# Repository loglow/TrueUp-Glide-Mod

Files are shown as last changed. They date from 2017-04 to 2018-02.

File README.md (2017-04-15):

# TrueUp-Glide-Mod

This is a modification of the [TrueUp Glide](http://www.openbuilds.com/builds/trueup-glide.3938/) 3D printer design by [Keith Davis](http://www.openbuilds.com/members/keith-davis.246/).

This mod differs from the source build in the following respects:

- Utilizes the [Bondtech BMG Extruder](http://shop.bondtech.se/ec/extruders/bmg-extruder.html) module
- Incorporates a [Raspberry Pi 3 Model B](https://www.raspberrypi.org/products/raspberry-pi-3-model-b/) running [OctoPi](https://octopi.octoprint.org) into the control box
- Includes an optional printed enclosure for the power supply unit
- Consolidates several printed parts and introduces several new ones
- Utilizes heat-set threaded inserts in several instances
- Minor redesign and dimensional cleanup of most printed parts
- Dimensionally accurate and logically organized master SketchUp file

This build is currently a work-in-progress and has not yet been fully tested. The complete BOM will be added in spreadsheet form as soon as possible.

## License

Adapted from [TrueUp Glide](http://www.openbuilds.com/builds/trueup-glide.3938/) and [TrueUp Kit Version](http://www.openbuilds.com/builds/trueup-kit-version.4779/) by [Keith Davis](http://www.openbuilds.com/members/keith-davis.246/) and licensed [Creative Commons BY-NC-SA](https://creativecommons.org/licenses/by-nc-sa/4.0/)

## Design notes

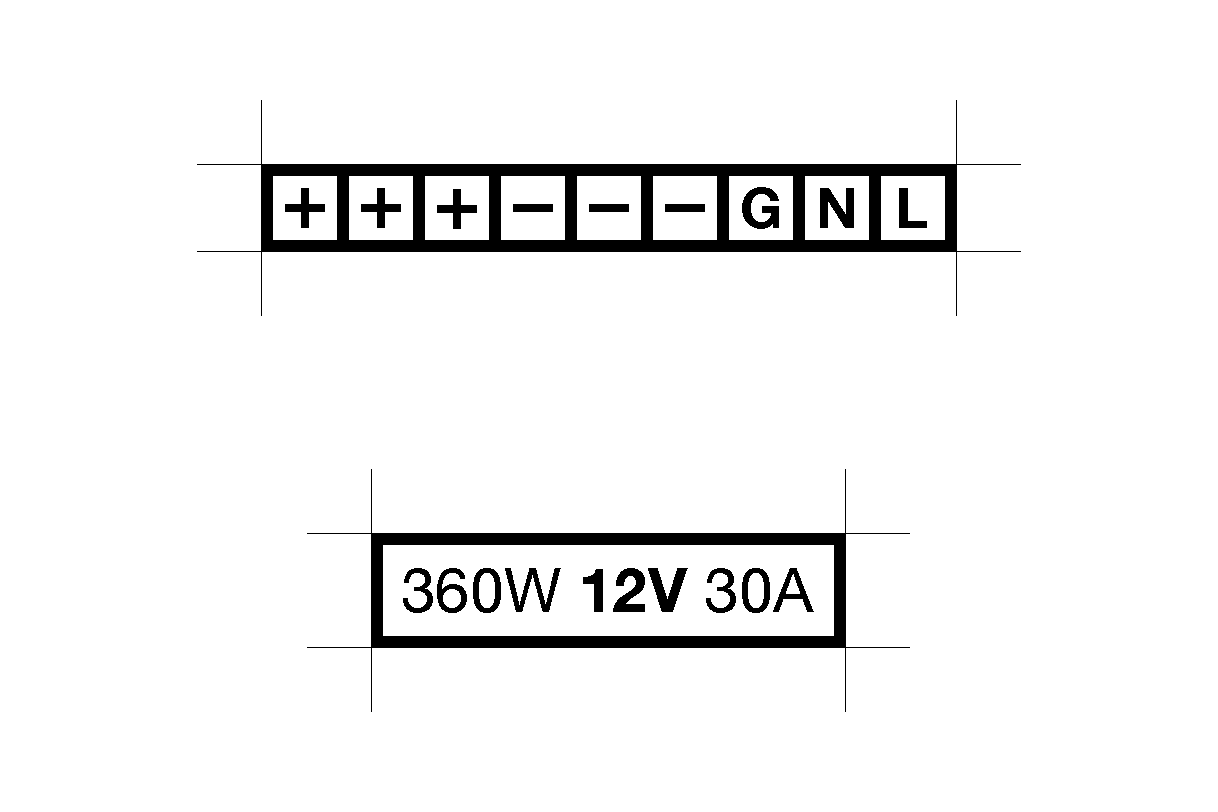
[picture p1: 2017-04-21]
PSU Label.png

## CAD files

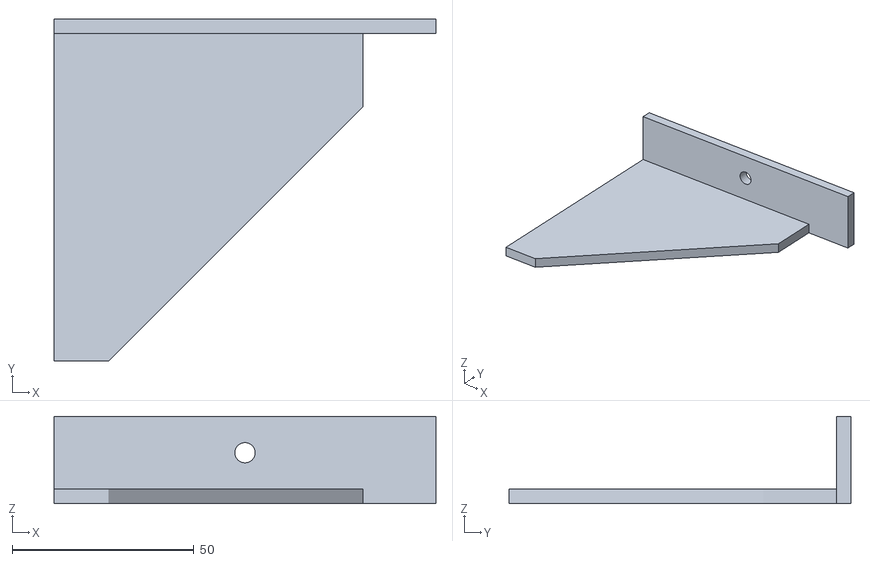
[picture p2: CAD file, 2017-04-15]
STL/Y Assembly Jig.stl
105.0 x 94.0 x 24.0

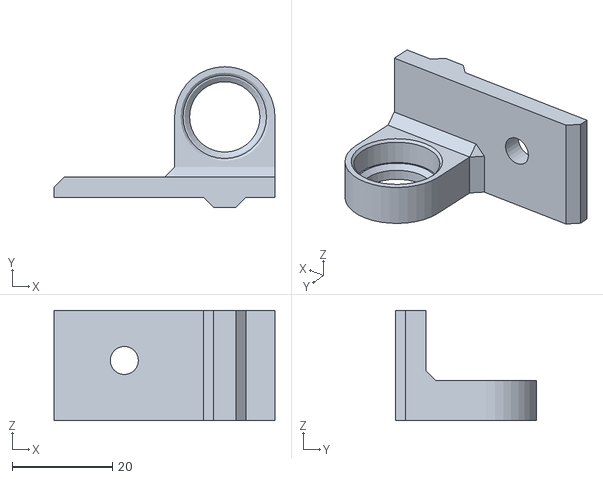
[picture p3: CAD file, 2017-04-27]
STL/Z Protector Bracket, Right.stl
44.0 x 28.0 x 22.0

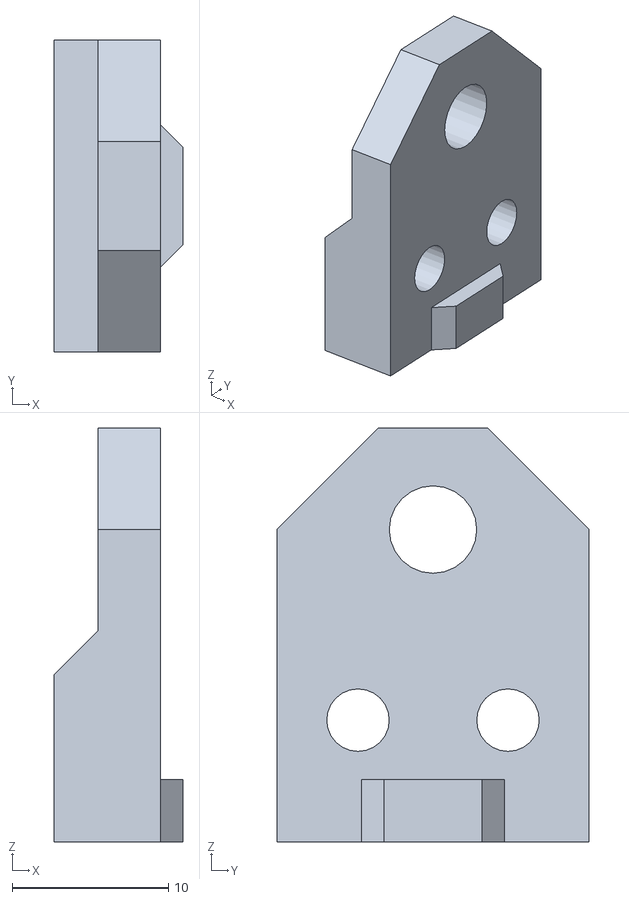
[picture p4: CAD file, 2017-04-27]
STL/Y Endstop Bracket.stl
8.26 x 20.0 x 26.5

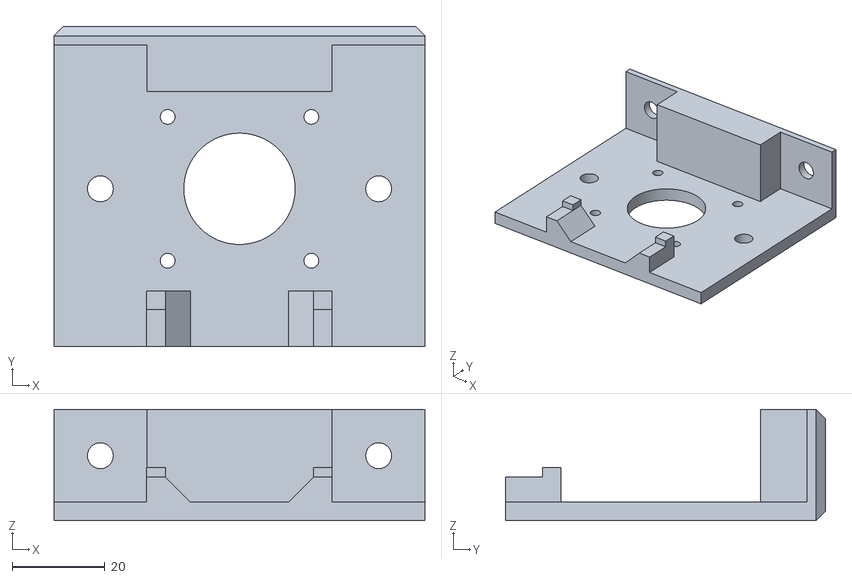
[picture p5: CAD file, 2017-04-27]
STL/Y Motor Mount.stl
80.0 x 69.0 x 24.0

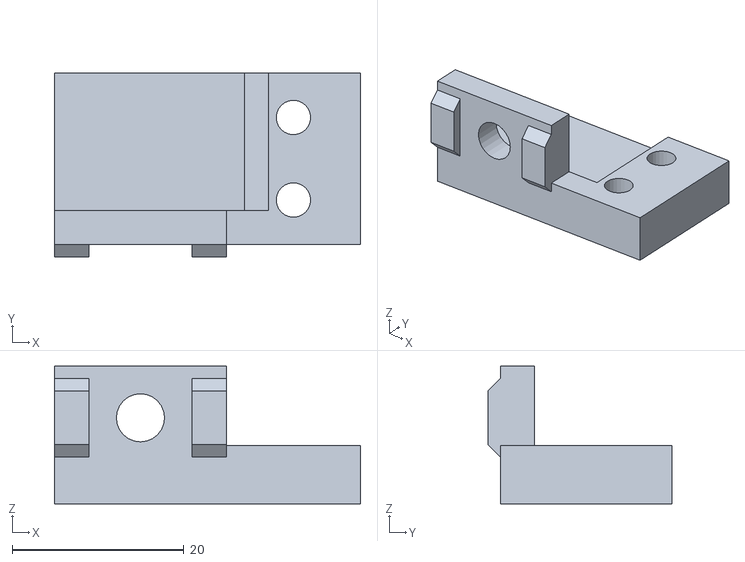
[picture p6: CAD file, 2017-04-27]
STL/X Endstop Bracket.stl
35.6 x 21.5 x 16.0

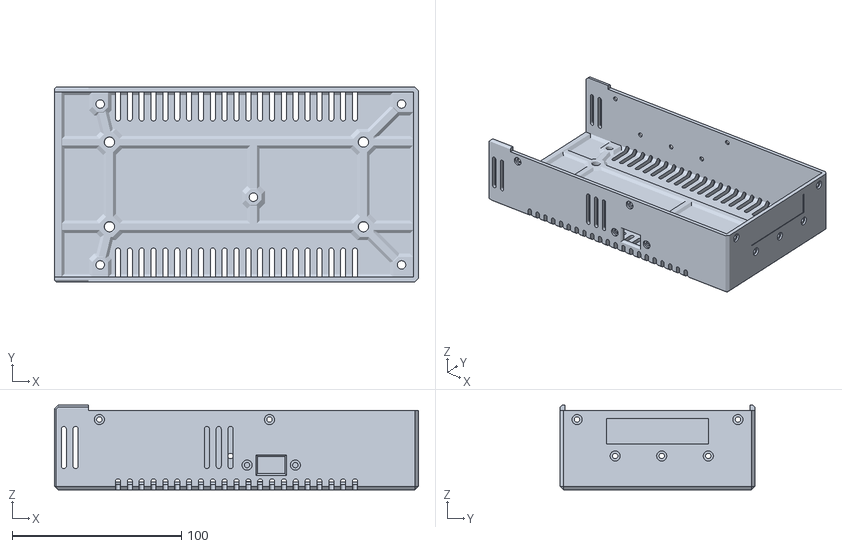
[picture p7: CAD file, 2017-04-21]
STL/PSU Bottom.stl
215.0 x 115.0 x 50.0

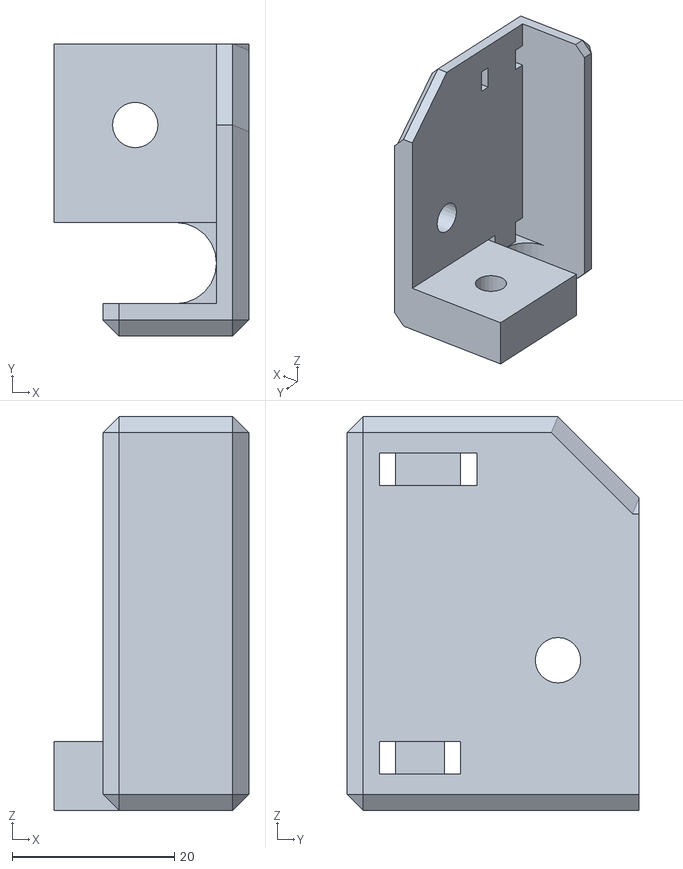
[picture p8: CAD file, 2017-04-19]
STL/X Belt Idler Bracket, Left.stl
24.0 x 36.0 x 48.5

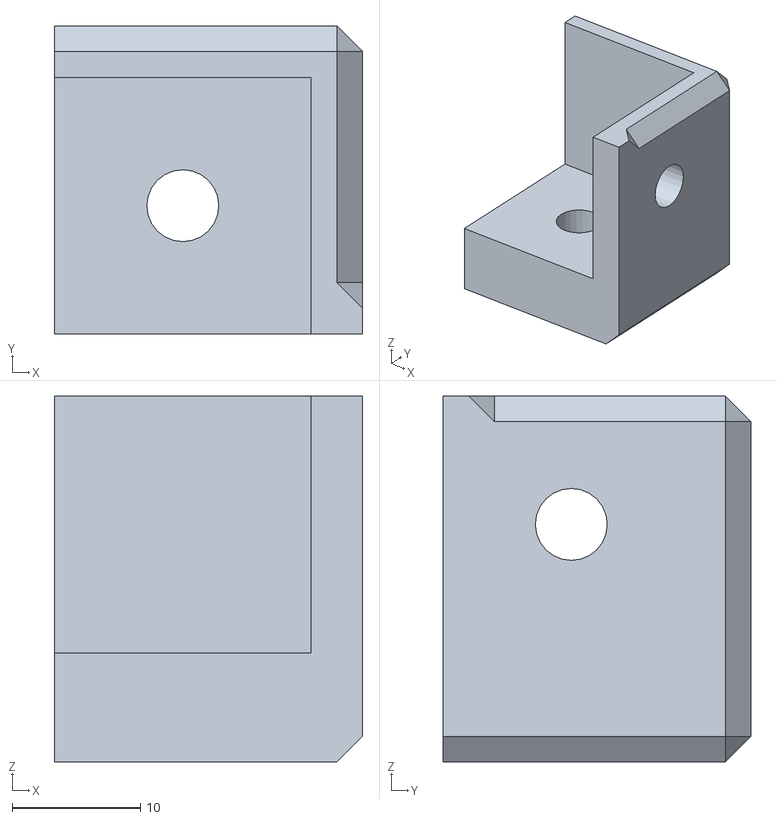
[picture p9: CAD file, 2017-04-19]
STL/X Belt Idler Bracket, Right.stl
24.0 x 24.0 x 28.5

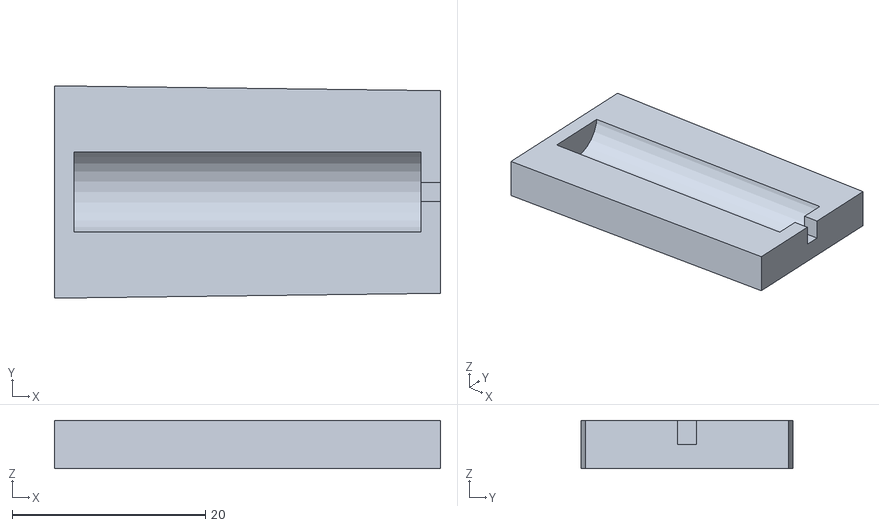
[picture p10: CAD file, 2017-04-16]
STL/Glide Bushing.stl
40.0 x 22.0 x 5.00

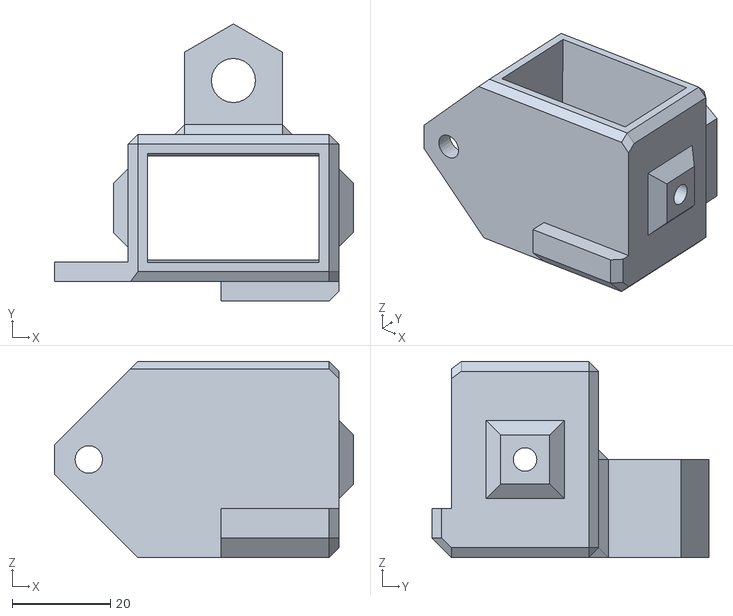
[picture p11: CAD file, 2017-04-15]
STL/Z Glide Body, Right.stl
61.0 x 56.5 x 40.0

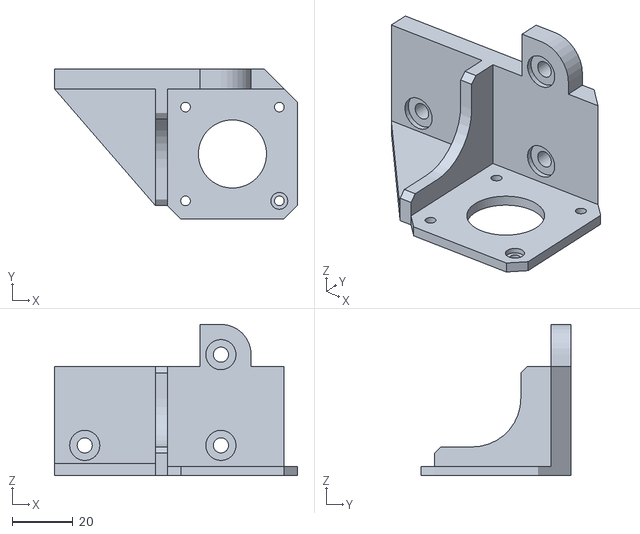
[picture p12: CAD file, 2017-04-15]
STL/Bondtech BMG Extruder Mount.stl
80.3 x 49.6 x 50.0

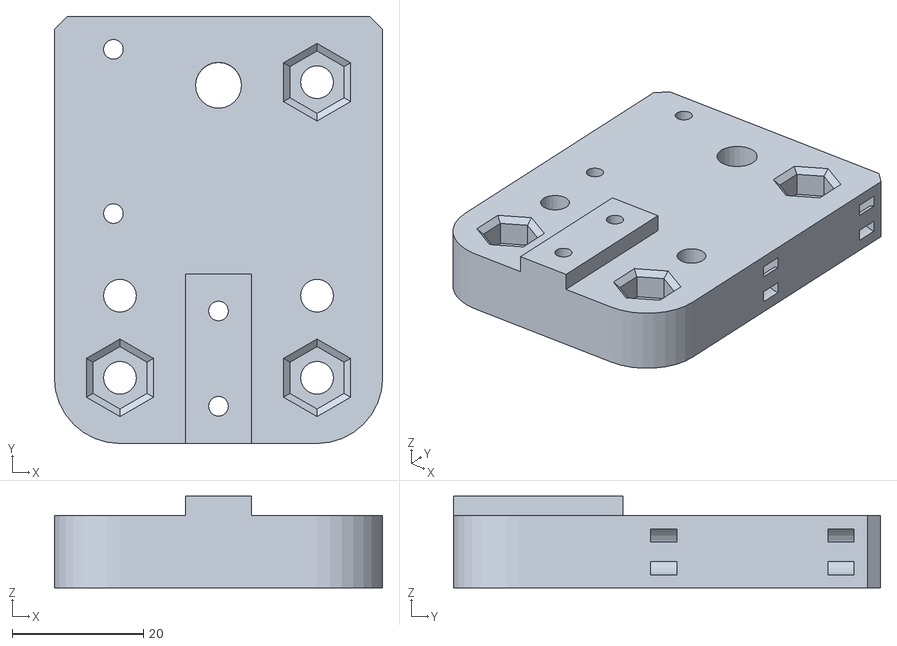
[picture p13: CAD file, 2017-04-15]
STL/X Carriage.stl
50.0 x 65.0 x 14.0

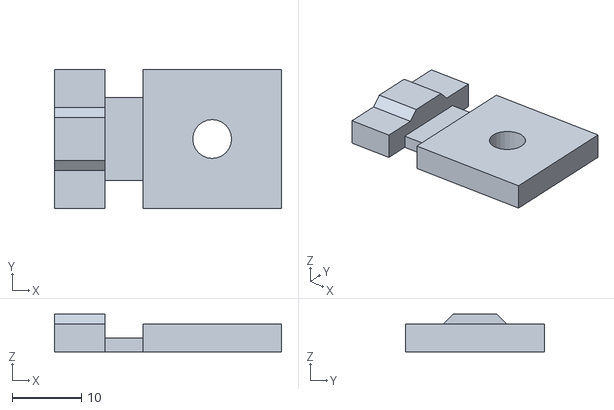
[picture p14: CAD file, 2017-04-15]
STL/Tie Bracket.stl
32.8 x 20.0 x 5.45

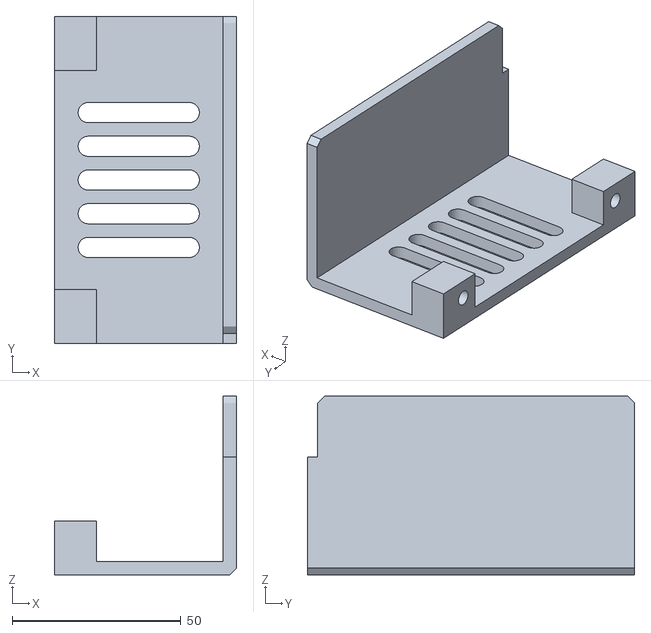
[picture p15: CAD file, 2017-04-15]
STL/PSU Cover.stl
54.0 x 97.0 x 53.0

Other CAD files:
STL/Z Protector Bracket, Left.stl
STL/PSU Mount.stl
STL/Frame Foot.stl
STL/MKS Mount.stl
STL/Control Box Fan Mount.stl
STL/Control Box, Bottom.stl
STL/Control Box, Front.stl
STL/Control Box, Left.stl
STL/Control Box, Right.stl
STL/Control Box, Top.stl
STL/Corner Nut Anchor.stl
STL/Crossover Cover.stl
STL/Front Foot.stl
STL/Handle.stl
STL/Loom Cap.stl
STL/M8 Nut Keeper.stl
STL/PSU Top.stl
STL/Print Fan Nozzle.stl
STL/Print Fan Top.stl
STL/Spool Holder.stl
STL/Spool Mount.stl
STL/Top Corner, Left.stl
STL/Top Corner, Right.stl
STL/X Belt Keeper.stl
STL/X Leveling Jig.stl
STL/X Motor Mount.stl
STL/Y Belt Keeper Flat.stl
STL/Y Belt Keeper Spacer.stl
STL/Y Belt Keeper Teeth.stl
STL/Y Center.stl
STL/Y Idler Bracket.stl
STL/Y Mount Bracket.stl
STL/Z Bearing Mount.stl
STL/Z Endstop Bracket.stl
STL/Z Endstop Screw, Lower.stl
STL/Z Endstop Screw, Upper.stl
STL/Z Glide Body, Left.stl
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

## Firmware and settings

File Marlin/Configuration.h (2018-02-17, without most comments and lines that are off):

#define CONFIGURATION_H
#define CONFIGURATION_H_VERSION 010107
#define STRING_CONFIG_H_AUTHOR "(Daniel Gilbert, 2018-02-16)" // Who made the changes.
#define SHOW_BOOTSCREEN
#define STRING_SPLASH_LINE1 SHORT_BUILD_VERSION // will be shown during bootup in line 1
#define STRING_SPLASH_LINE2 WEBSITE_URL         // will be shown during bootup in line 2
#define SERIAL_PORT 0
#define BAUDRATE 250000
  #define MOTHERBOARD BOARD_RAMPS_14_EFB
#define CUSTOM_MACHINE_NAME "TrueUp Glide"
#define MACHINE_UUID "6b72f3d6-61a9-46b7-b8c5-1d304e1b14a3"
#define EXTRUDERS 1
#define DEFAULT_NOMINAL_FILAMENT_DIA 1.75
#define POWER_SUPPLY 1
#define TEMP_SENSOR_0 5
#define TEMP_SENSOR_1 0
#define TEMP_SENSOR_2 0
#define TEMP_SENSOR_3 0
#define TEMP_SENSOR_4 0
#define TEMP_SENSOR_BED 11
#define DUMMY_THERMISTOR_998_VALUE 25
#define DUMMY_THERMISTOR_999_VALUE 100
#define MAX_REDUNDANT_TEMP_SENSOR_DIFF 10
#define TEMP_RESIDENCY_TIME 10  // (seconds)
#define TEMP_HYSTERESIS 3       // (degC) range of +/- temperatures considered "close" to the target one
#define TEMP_WINDOW     1       // (degC) Window around target to start the residency timer x degC early.
#define TEMP_BED_RESIDENCY_TIME 10  // (seconds)
#define TEMP_BED_HYSTERESIS 3       // (degC) range of +/- temperatures considered "close" to the target one
#define TEMP_BED_WINDOW     1       // (degC) Window around target to start the residency timer x degC early.
#define HEATER_0_MINTEMP 5
#define HEATER_1_MINTEMP 5
#define HEATER_2_MINTEMP 5
#define HEATER_3_MINTEMP 5
#define HEATER_4_MINTEMP 5
#define BED_MINTEMP 5
#define HEATER_0_MAXTEMP 285
#define HEATER_1_MAXTEMP 275
#define HEATER_2_MAXTEMP 275
#define HEATER_3_MAXTEMP 275
#define HEATER_4_MAXTEMP 275
#define BED_MAXTEMP 120
#define PIDTEMP
#define BANG_MAX 255     // Limits current to nozzle while in bang-bang mode; 255=full current
#define PID_MAX BANG_MAX // Limits current to nozzle while PID is active (see PID_FUNCTIONAL_RANGE below); 255=full current
#define PID_K1 0.95      // Smoothing factor within the PID
  #define PID_FUNCTIONAL_RANGE 10 // If the temperature difference between the target temperature and the actual temperature
  #define  DEFAULT_Kp 18.82
  #define  DEFAULT_Ki 1.24
  #define  DEFAULT_Kd 71.69
#define PIDTEMPBED
#define MAX_BED_POWER 255 // limits duty cycle to bed; 255=full current
  #define  DEFAULT_bedKp 302.66
  #define  DEFAULT_bedKi 59.21
  #define  DEFAULT_bedKd 386.81
#define PREVENT_COLD_EXTRUSION
#define EXTRUDE_MINTEMP 170
#define PREVENT_LENGTHY_EXTRUDE
#define EXTRUDE_MAXLENGTH 200
#define THERMAL_PROTECTION_HOTENDS // Enable thermal protection for all extruders
#define THERMAL_PROTECTION_BED     // Enable thermal protection for the heated bed
#define USE_XMIN_PLUG
#define USE_YMIN_PLUG
#define USE_ZMIN_PLUG
#define ENDSTOPPULLUPS // Comment this out (using // at the start of the line) to disable the endstop pullup resistors
#define X_MIN_ENDSTOP_INVERTING false // set to true to invert the logic of the endstop.
#define Y_MIN_ENDSTOP_INVERTING false // set to true to invert the logic of the endstop.
#define Z_MIN_ENDSTOP_INVERTING false // set to true to invert the logic of the endstop.
#define X_MAX_ENDSTOP_INVERTING false // set to true to invert the logic of the endstop.
#define Y_MAX_ENDSTOP_INVERTING false // set to true to invert the logic of the endstop.
#define Z_MAX_ENDSTOP_INVERTING false // set to true to invert the logic of the endstop.
#define Z_MIN_PROBE_ENDSTOP_INVERTING false // set to true to invert the logic of the probe.
#define DEFAULT_AXIS_STEPS_PER_UNIT   { 100, 100, 3200, 415 }
#define DEFAULT_MAX_FEEDRATE          { 250, 250, 4, 25 }
#define DEFAULT_MAX_ACCELERATION      { 1000, 1000, 5, 1000 }
#define DEFAULT_ACCELERATION          500    // X, Y, Z and E acceleration for printing moves
#define DEFAULT_RETRACT_ACCELERATION  500    // E acceleration for retracts
#define DEFAULT_TRAVEL_ACCELERATION   1000    // X, Y, Z acceleration for travel (non printing) moves
#define DEFAULT_XJERK                 20.0
#define DEFAULT_YJERK                 20.0
#define DEFAULT_ZJERK                  0.4
#define DEFAULT_EJERK                  5.0
#define Z_MIN_PROBE_USES_Z_MIN_ENDSTOP_PIN
#define X_PROBE_OFFSET_FROM_EXTRUDER 10  // X offset: -left  +right  [of the nozzle]
#define Y_PROBE_OFFSET_FROM_EXTRUDER 10  // Y offset: -front +behind [the nozzle]
#define Z_PROBE_OFFSET_FROM_EXTRUDER 0   // Z offset: -below +above  [the nozzle]
#define XY_PROBE_SPEED 8000
#define Z_PROBE_SPEED_FAST HOMING_FEEDRATE_Z
#define Z_PROBE_SPEED_SLOW (Z_PROBE_SPEED_FAST / 2)
#define Z_CLEARANCE_DEPLOY_PROBE   10 // Z Clearance for Deploy/Stow
#define Z_CLEARANCE_BETWEEN_PROBES  5 // Z Clearance between probe points
#define Z_PROBE_OFFSET_RANGE_MIN -20
#define Z_PROBE_OFFSET_RANGE_MAX 20
#define X_ENABLE_ON 0
#define Y_ENABLE_ON 0
#define Z_ENABLE_ON 0
#define E_ENABLE_ON 0 // For all extruders
#define DISABLE_X false
#define DISABLE_Y false
#define DISABLE_Z false
#define DISABLE_E false // For all extruders
#define DISABLE_INACTIVE_EXTRUDER true // Keep only the active extruder enabled.
#define INVERT_X_DIR false
#define INVERT_Y_DIR false
#define INVERT_Z_DIR false
#define INVERT_E0_DIR true
#define INVERT_E1_DIR false
#define INVERT_E2_DIR false
#define INVERT_E3_DIR false
#define INVERT_E4_DIR false
#define Z_HOMING_HEIGHT 1  // (in mm) Minimal z height before homing (G28) for Z clearance above the bed, clamps, ...
#define X_HOME_DIR -1
#define Y_HOME_DIR -1
#define Z_HOME_DIR -1
#define X_BED_SIZE 194
#define Y_BED_SIZE 178
#define X_MIN_POS 0
#define Y_MIN_POS 0
#define Z_MIN_POS 0
#define X_MAX_POS X_BED_SIZE
#define Y_MAX_POS Y_BED_SIZE
#define Z_MAX_POS 200
#define MIN_SOFTWARE_ENDSTOPS
  #define MIN_SOFTWARE_ENDSTOP_X
  #define MIN_SOFTWARE_ENDSTOP_Y
  #define MIN_SOFTWARE_ENDSTOP_Z
#define MAX_SOFTWARE_ENDSTOPS
  #define MAX_SOFTWARE_ENDSTOP_X
  #define MAX_SOFTWARE_ENDSTOP_Y
  #define MAX_SOFTWARE_ENDSTOP_Z
#define HOMING_FEEDRATE_XY (50*60)
#define HOMING_FEEDRATE_Z  (4*60)
#define EEPROM_CHITCHAT   // Give feedback on EEPROM commands. Disable to save PROGMEM.
#define HOST_KEEPALIVE_FEATURE        // Disable this if your host doesn't like keepalive messages
#define DEFAULT_KEEPALIVE_INTERVAL 2  // Number of seconds between "busy" messages. Set with M113.
#define BUSY_WHILE_HEATING            // Some hosts require "busy" messages even during heating
#define PREHEAT_1_TEMP_HOTEND 180
#define PREHEAT_1_TEMP_BED     70
#define PREHEAT_1_FAN_SPEED     0 // Value from 0 to 255
#define PREHEAT_2_TEMP_HOTEND 240
#define PREHEAT_2_TEMP_BED    110
#define PREHEAT_2_FAN_SPEED     0 // Value from 0 to 255
#define NOZZLE_PARK_FEATURE
  #define NOZZLE_PARK_POINT { (X_MIN_POS + 10), (Y_MAX_POS - 10), 20 }
  #define NOZZLE_PARK_XY_FEEDRATE 100   // X and Y axes feedrate in mm/s (also used for delta printers Z axis)
  #define NOZZLE_PARK_Z_FEEDRATE 5      // Z axis feedrate in mm/s (not used for delta printers)
#define PRINTJOB_TIMER_AUTOSTART
#define LCD_LANGUAGE en
#define DISPLAY_CHARSET_HD44780 JAPANESE
#define SOFT_PWM_SCALE 0
#define SERVO_DELAY { 300 }

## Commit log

2017-04-16 changed glide bushing to be 1 mm wider
    [Glide Bushing.stl]
2017-04-18 moved location of Y belt keeper for clearance
2017-04-18 modified x belt idler brackets, left for limit switch clearance, both for extrusion end screw holes
    [X Belt Idler Bracket, Left.stl, X Belt Idler Bracket, Right.stl]
2017-04-19 increased x endstop clearance by 10 mm, separated x endstop bracket (more like original), simplified x idler brackets
    [X Belt Idler Bracket, Left.stl, X Belt Idler Bracket, Right.stl, X Endstop Bracket.stl]
2017-04-20 Tweaks to x endstop bracket, uses threaded inserts now
    [X Endstop Bracket.stl]
2017-04-21 PSU bottom case minor wall thickness fix
    [PSU Bottom.stl]
2017-04-21 PSU labels update, added PNG for thermal printing
2017-04-26 adding default Marlin configuration file, unmodified in this commit
    [Configuration.h]
2017-04-26 customized Marlin configuration file
    [Configuration.h]
2017-04-27 separated out v-slot endstop brackets so their positions can be adjusted
    [X Endstop Bracket.stl, Y Endstop Bracket.stl, Y Motor Mount.stl]
2017-04-27 added ball bearings into Z protector brackets, update master skp
    [Z Protector Bracket, Left.stl, Z Protector Bracket, Right.stl]
2017-04-27 changed Z protector brackets for easier printing
    [Z Protector Bracket, Left.stl, Z Protector Bracket, Right.stl]
2017-04-29 firmware configuration tweaks
    [Configuration.h]
2018-02-17 Updated Marlin firmware
    [Configuration.h]

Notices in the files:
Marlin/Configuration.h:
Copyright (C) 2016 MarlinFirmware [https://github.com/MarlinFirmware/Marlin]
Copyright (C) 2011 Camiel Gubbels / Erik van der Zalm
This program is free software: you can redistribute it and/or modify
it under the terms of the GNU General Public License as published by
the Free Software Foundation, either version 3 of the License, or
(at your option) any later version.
